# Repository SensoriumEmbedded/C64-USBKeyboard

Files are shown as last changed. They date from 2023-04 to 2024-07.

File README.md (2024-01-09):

# C64-USBKeyboard

## USB keyboard interface for Commodore 64

**Original code and C64 Key Pos Mapping:**
* C64keyboard - Commodore Keyboard library
* Copyright (c) 2022 Hartland PC LLC, Written by Robert VanHazinga

**Rewritten/updated for Teensy 3.6/4.1:**
* Copyright (c) 2023 Sensorium Embedded, Written by Travis Smith
* Raw keypresss detection for improved emulation
* Ability to Shift special macro keys to c64 (F2/4/6/8, Cursor up/left, etc) 
* Diagnostics loopback emulation
* Symbol mapping for readability and easy editing
* Improved code clarity, fixed bugs
* PCB designed/added

PCB assembly instructions can be found **[here.](PCB/PCB_Assembly.md)**

Questions?  Send e-mail to [Travis @ Sensorium](mailto:travis@sensoriumembedded.com)

Stand-alone and in-system pictures below.  Note that I have sockets above and below the Teensy module in my build. Actual build per BOM using headers will make it sit much lower (similar to the MT8808 chip)
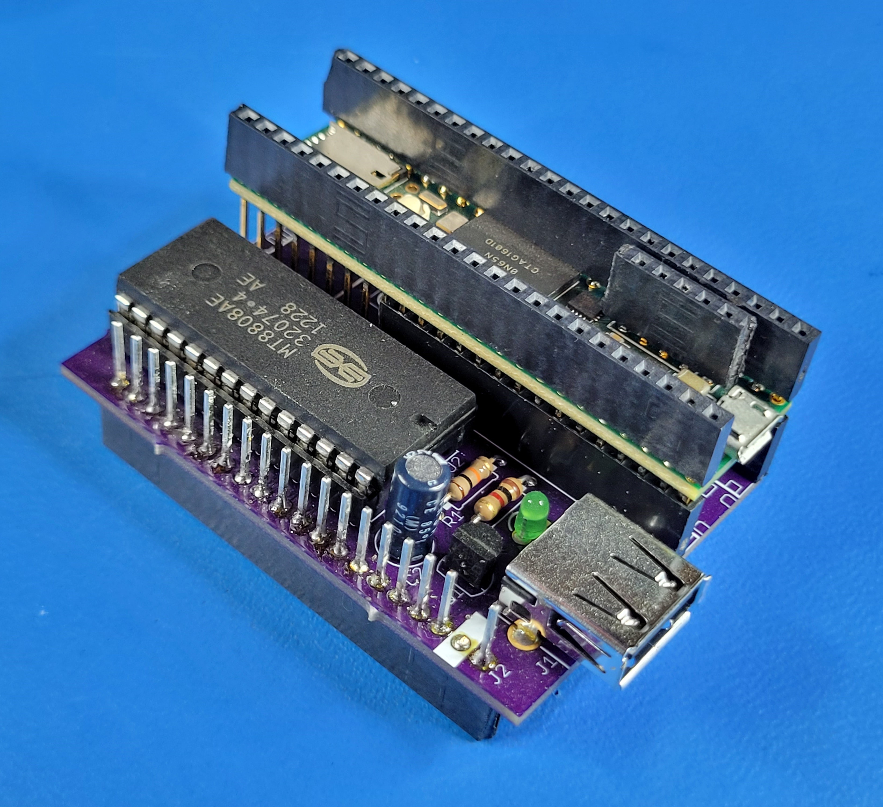
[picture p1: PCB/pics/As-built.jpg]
As-built
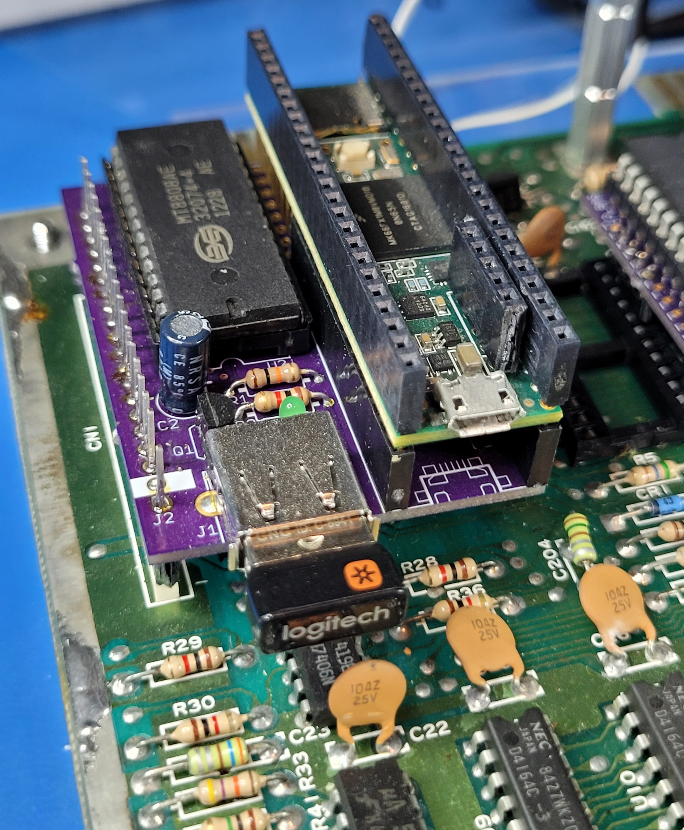
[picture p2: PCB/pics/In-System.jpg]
In-System
||| 
|:--:|:--:|

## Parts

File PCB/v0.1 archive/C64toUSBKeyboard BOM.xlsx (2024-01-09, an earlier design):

Qty | Ref Des | Value | Description | Manuf | MPN | DigiKey PN/link | Notes
1 |  | PCB | 2 layer 0.063" PCB | OSH Park, JLCPCB, PCBWay | v0.1 |  | C64toUSBKeyboard.0.1.gerbers.zip or https://oshpark.com/shared_projects/wqtal8dL
1 | R1 | 10k | RES 10K OHM 5% 1/4W AXIAL | Stackpole | CF14JT10K0 | CF14JT10K0CT-ND (https://www.digikey.com/en/products/detail/stackpole-electronics-inc/CF14JT10K0/1741265) | Multiple subs available
1 | R2 | 1k | RES 1K OHM 5% 1/4W AXIAL | Stackpole | CF14JT1K00 | CF14JT1K00CT-ND (https://www.digikey.com/en/products/detail/stackpole-electronics-inc/CF14JT1K00/1741314) | Multiple subs available
1 | J2 | 20p Female header | 20 Position Receptacle Connector 0.100" (2.54mm) Through Hole Tin w/ long pins | Samtec Inc. | SSQ-120-03-T-S | SAM1206-20-ND (https://www.digikey.com/en/products/detail/samtec-inc/SSQ-120-03-T-S/1111938) | Allows for passthrough to use simultaneous with commodore kbd, otherwise can just use standard female or cut leads
1 | C2 | 22uF | 22-100uF CPOL-US E2.5-6 Radial Electrolytic Cap | Panasonic | ECA-1EM220I | P19523CT-ND (https://www.digikey.com/en/products/detail/panasonic-electronic-components/ECA-1EM220I/2688679) | Multiple subs available
1 | Q1 | 2N3904 | NPN TRANSISTOR 2N3904/TO92 | Fairchild | 2N3904 | 3845-2N3904-ND (https://www.digikey.com/en/products/detail/galco-industrial-electronics/2N3904/15657702) | Multiple subs available
1 | C1 | DNS | Unused, Do Not Stuff
1 | D1 | LED-3MM-GRN | LED 3.1MM PTH | Lumex Opto | SSL-LX3044GD | 67-1060-ND (https://www.digikey.com/en/products/detail/lumex-opto-components-inc/SSL-LX3044GD/270858) | Sq hole/short lead/flat side/-/Cathode
1 | U2 | MT8808 | MITEL/ZARLINK MT8808AE DIP-28 ISO-CMOS 8 x 8 Analog Switch | MITEL/ZARLINK | MT8808AE | Multiple on eBay | No longer manufactured, but widely available.
1 | JP1 | SHORTSMT | Unused, Do Not Stuff |  |  |  | Leave this shorted, as designed
1 | U1 | TEENSY_4.1 | Teensy 4.1 Devel Board | PJRC (https://www.pjrc.com/store) | TEENSY41 or TEENSY41_NE (https://www.pjrc.com/store/teensy41.html) | 1568-DEV-16771-ND (https://www.digikey.com/en/products/detail/sparkfun-electronics/DEV-16771/12180099) | Teensy 3.6 would also work, but discontinued Teensy 4.1 with or without Ethernet will also work can order _PINS version to include soldered headers
2 | U1- Hdr 1/2 | 24p headers | CONN HEADER VERT 1x24 POS 2.54mm (0.1") | Würth | 61302411121 | 732-5331-ND (https://www.digikey.com/en/products/detail/w%C3%BCrth-elektronik/61302411121/4846867) | 24 pin headers to pass control signals from Teensy to PCB. Not needed with _PINS version of Teensy 4.1
1 | U1- Hdr 3 | 5p header | CONN HEADER VERT 1x5 POS 2.54mm (0.1") | Würth | 61300511121 | 732-5318-ND (https://www.digikey.com/en/products/detail/w%C3%BCrth-elektronik/61300511121/4846831) | 5 pin header to pass USB host signals from Teensy to PCB
1 | J1 | USB-A Fem | AMP connector | TE/AMP | 292303-1 | A31726-ND (https://www.digikey.com/en/products/detail/te-connectivity-amp-connectors/292303-1/773786)

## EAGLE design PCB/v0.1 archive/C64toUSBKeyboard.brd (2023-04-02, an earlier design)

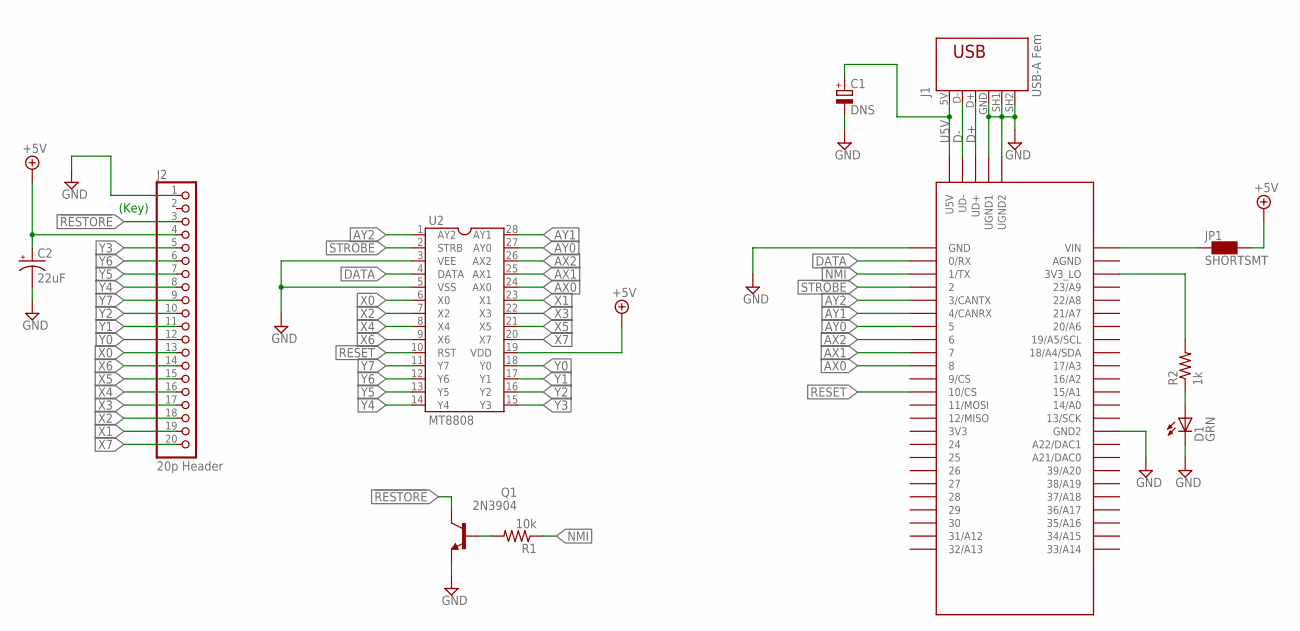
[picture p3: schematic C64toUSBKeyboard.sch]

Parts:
C1: DNS; A/3216-18W
C2: 22uF; E2,5-6
D1: GRN; LED-3MM-PTH
J1: USB-A Fem; USB
J2: 20p Header; 1X20_ROUND
JP1: SHORTSMT; SHORT
Q1: 2N3904; TO92
R1: 10k; 0207/10
R2: 1k; 0207/10
U1: TEENSY_3.6_4.1; TEENSY_3.5/3.6
U2: MT8808; DIL28-6

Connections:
3V3: R2.2, U1.3V3_LO
5V_TEENSY: JP1.1, U1.VIN
!RESTORE: J2.3, Q1.1 (C)
+5V: C2.+, J2.4, JP1.2, U2.19 (VDD)
AX0: U1.8, U2.24 (AX0)
AX1: U1.7, U2.25 (AX1)
AX2: U1.6, U2.26 (AX2)
AY0: U1.5, U2.27 (AY0)
AY1: U1.4/CANRX, U2.28 (AY1)
AY2: U1.3/CANTX, U2.1 (AY2)
D+: J1.D+ (3), U1.UD+
D-: J1.D- (2), U1.UD-
DATA: U1.0/RX, U2.4 (DATA)
GND: C1.-, C2.-, D1.K (C), J1.GND (4), J1.SH1 (5), J1.SH2 (6), J2.1, Q1.3 (E), U1.GND, U1.GND2, U1.UGND1, U1.UGND2, U2.3 (VEE), U2.5 (VSS)
LED_R: D1.A, R2.1
NMI: R1.1, U1.1/TX
NMI_R: Q1.2 (B), R1.2
RESET: U1.10/CS, U2.10 (RST)
STROBE: U1.2, U2.2 (STRB)
U5V: C1.+, J1.5V (1), U1.U5V
X0: J2.13, U2.6 (X0)
X1: J2.19, U2.23 (X1)
X2: J2.18, U2.7 (X2)
X3: J2.17, U2.22 (X3)
X4: J2.16, U2.8 (X4)
X5: J2.15, U2.21 (X5)
X6: J2.14, U2.9 (X6)
X7: J2.20, U2.20 (X7)
Y0: J2.12, U2.18 (Y0)
Y1: J2.11, U2.17 (Y1)
Y2: J2.10, U2.16 (Y2)
Y3: J2.5, U2.15 (Y3)
Y4: J2.8, U2.14 (Y4)
Y5: J2.7, U2.13 (Y5)
Y6: J2.6, U2.12 (Y6)
Y7: J2.9, U2.11 (Y7)

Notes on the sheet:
(Key)

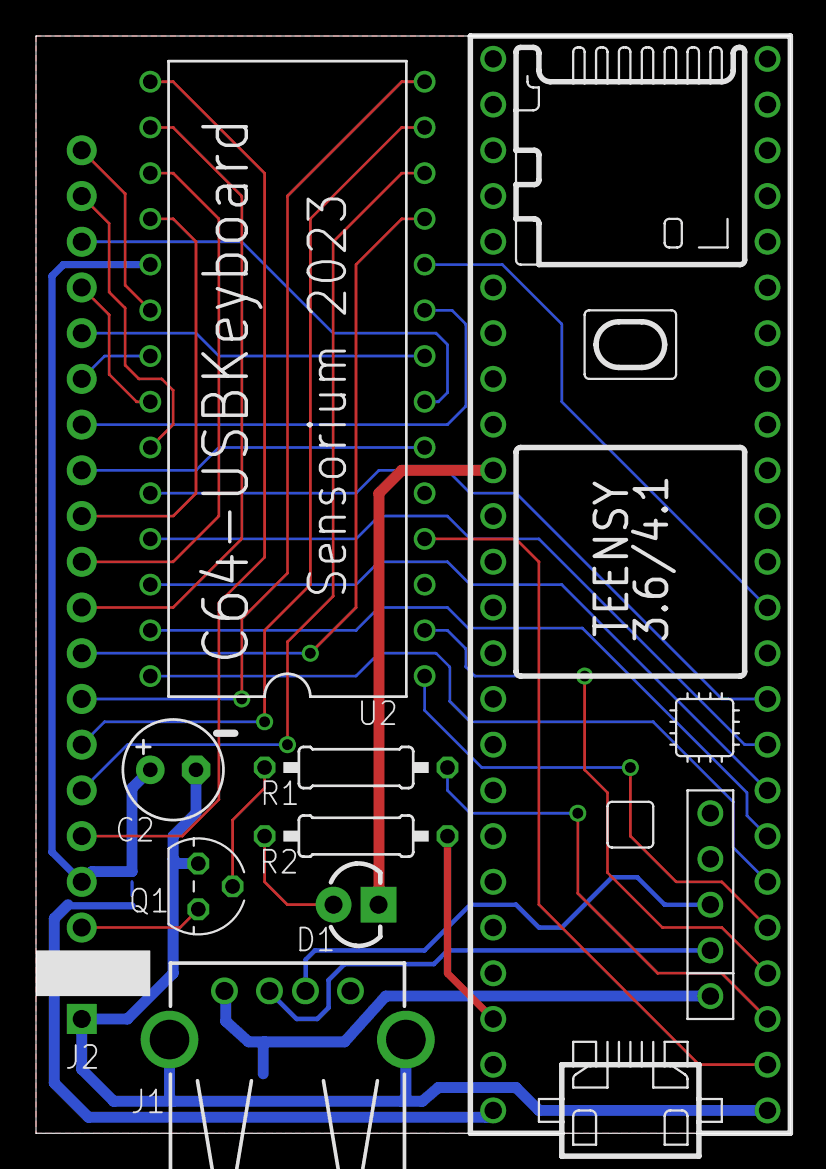
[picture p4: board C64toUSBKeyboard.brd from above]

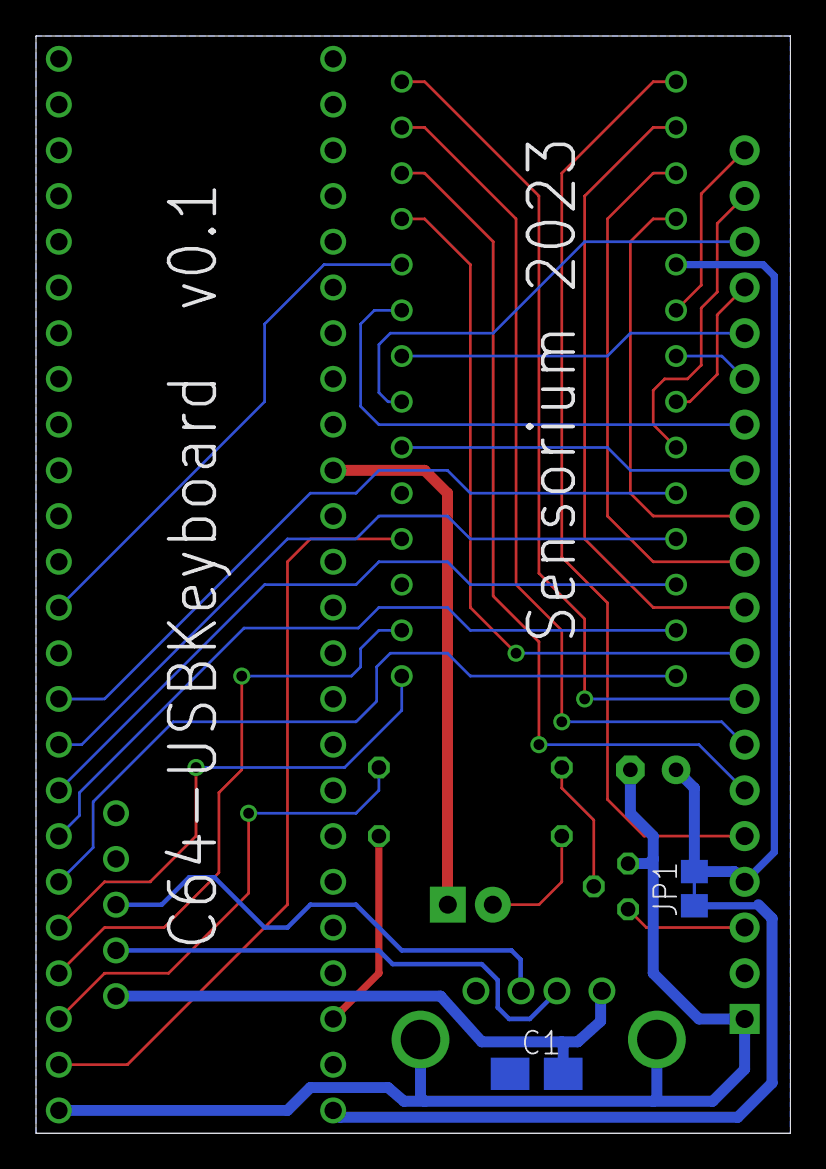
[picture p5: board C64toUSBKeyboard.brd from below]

Board: 2 copper layers, 41.9 x 61.0 mm, 11 parts (2 on the bottom side), 36 nets.

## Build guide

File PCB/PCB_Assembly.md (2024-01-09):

# C64 USB Keyboard PCB Assembly Instructions:

If there are additional questions, feel free to [contact me](mailto:travis@sensoriumembedded.com).

## Tools/materials needed:
- Soldering iron/Solder (lead-free or otherwise)
- Wire cutters (aka Side Cutters, Dykes)
- Small knife (ie Exacto)
- Computer with [Arduino](https://www.arduino.cc/en/software) and the [Teensyduino app](https://www.pjrc.com/teensy/td_download.html) loaded.
- Parts listed in the [TeensyROM BOM](https://github.com/SensoriumEmbedded/C64-USBKeyboard/raw/main/PCB/v0.1%20archive/C64toUSBKeyboard%20BOM.xlsx)
  - Including bare PCB: [Link to design at OSH Park](https://oshpark.com/shared_projects/wqtal8dL)

## Teensy prep:
- Programming the Teensy is done via the micro-USB connector on the Teensy itself.  This can create a problem with the 5v supply from the USB port driving against the 5v supply from your C64. Depending on how often you plan to update the firmware, choose one of the following two options.
  - **Option 1 (recommended)**: For the ability to update firmware while connected to the C64 (with the C64 turned on, powering the Teensy), you’ll need to cut a small jumper on the bottom of the Teensy 4.1 itself, as shown in [this picture](https://raw.githubusercontent.com/SensoriumEmbedded/TeensyROM/main/media/Teensy/T41_pwr_cut.jpg).  This should be done prior to assembly since it is on the bottom of the Teensy module.  The jumper can remain cut and allows programming while powered from the C64 only.
  - **Option 2**: Remove the PCB from the C64 when programming the Teensy.  This will allow the USB 5v to power the Teensy for programming and not conflict with the C64 power.  When finished, disconnect the micro-USB connection and re-install in to your C64.  **Do not connect the Teensy to a modern computer and the C64 at the same time when using this option.**
 
## PCB Assembly

- All components (except resistors) must be installed in propper orientation/polarity.
  - See silkscreen markings for each component during installation.
  - Capacitor (C2): Negative mark on cap should match negative mark on PCB
  - LED (D1): Square hole = short lead = flat side = Cathode
- Note that the Teensy requires both the two 24 pin headers as well as a 5 pin header to connect to the PCB. The 5 pin header carries the USB host signals to the connector, **(very important)**
- The connector to the C64(J2) is the only one installed from the bottom.

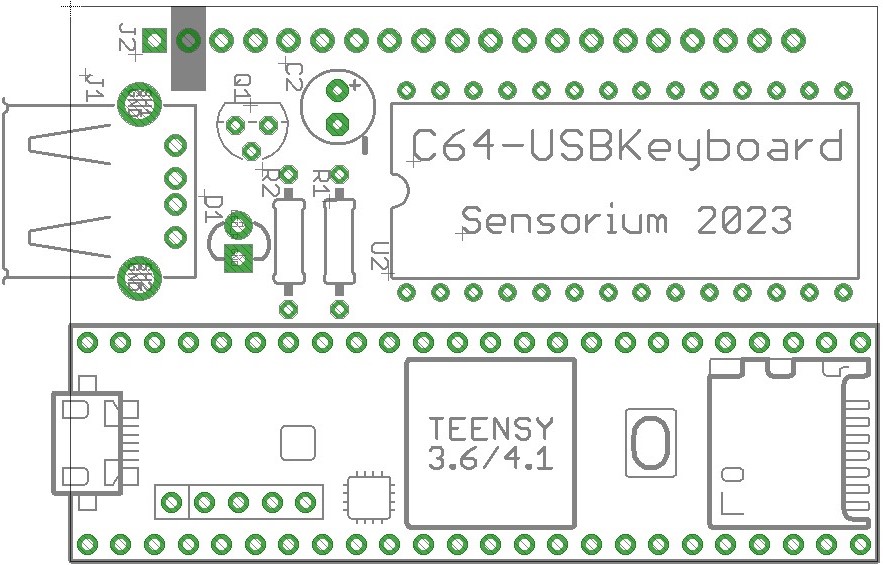
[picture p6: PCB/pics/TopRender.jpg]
TopRender


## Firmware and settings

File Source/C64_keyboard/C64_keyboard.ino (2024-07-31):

/*
  C64 USB keyboard - Commodore USB Keyboard Interface

  Rewritten for Teensy 3.6/4.1 and added:
    Raw keypresss detection, Shift special keys, symbol mapping, clarity, & bug fixes
    Copyright (c) 2023 Sensorium Embedded
    Written by Travis Smith

  Original code and C64 Key Pos Mapping:
    C64keyboard - Commodore Keyboard library
    Copyright (c) 2022 Hartland PC LLC
    Written by Robert VanHazinga

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
*/

#include "C64keyboard.h"
#include <USBHost_t36.h>

USBHost usb;
USBHub hub1(usb);
KeyboardController keyboard(usb);
USBHIDParser hid1(usb);
USBHIDParser hid2(usb);
IntervalTimer TODTimer;

bool CapsLockState=false; 
bool TODClockState=false;
bool TOD60n50HzSel=true;

extern "C" uint32_t set_arm_clock(uint32_t frequency);

void setup() 
{
   usb.begin();
   
   for ( uint8_t AddrBit = 0; AddrBit < 6; AddrBit++) pinMode(MT8808_ADDRESS_PINS[AddrBit], OUTPUT);
   pinMode(MT8808_STROBE_PIN, OUTPUT);
   pinMode(MT8808_DATA_PIN, OUTPUT);  
   pinMode(MT8808_RESET_PIN, OUTPUT); 
   pinMode(NMI_RESTORE_PIN, OUTPUT);  
   pinMode(INDICATOR_LED_PIN, OUTPUT);
   pinMode(EXT_TOD_CLK_OUT_PIN, OUTPUT);
   
   digitalWrite(NMI_RESTORE_PIN, LOW);
   digitalWrite(MT8808_STROBE_PIN, LOW);
   digitalWrite(INDICATOR_LED_PIN, HIGH);
   ResetMT8808();
   
   keyboard.attachRawPress(OnRawPress);
   keyboard.attachRawRelease(OnRawRelease);
   
   TODTimer.begin(ToggleTOD, IntervaluS_60Hz);  // Default to 60Hz
   
   Serial.begin(9600);
   
   Serial.println("\n\nUSB Keyboard -> Teensy -> MT8808 -> C64 keyboard input");
   digitalWrite(INDICATOR_LED_PIN, LOW);
   #ifdef ARDUINO_TEENSY41
      set_arm_clock(180000000);  //slow down Teensy 4.1 to match 3.6 default, otherwise too fast for 8808.  
         //Could add delays to SetSwitch, but slower CPU runs cooler and uses less power
      Serial.println("Teensy 4.1 found");
   #endif
}

void loop() 
{  
   usb.Task(); // Process USB tasks
}

void OnRawPress(uint8_t keycode) 
{
   digitalWrite(INDICATOR_LED_PIN, HIGH);
   Serial.print("Press==");
   ConvToC64Key(keycode, true);
}

void OnRawRelease(uint8_t keycode) 
{
   Serial.print("Release");
   ConvToC64Key(keycode, false);
   digitalWrite(INDICATOR_LED_PIN, LOW);
}

void ResetMT8808(void) 
{
   digitalWrite(MT8808_RESET_PIN, HIGH);
   digitalWrite(MT8808_RESET_PIN,  LOW);
   CapsLockState = false;
}

void ConvToC64Key(uint8_t KeyCode, bool KeyIsPressed) 
{
   Serial.printf ("=> USB Code: %d=0x%X, Press: %d\n", KeyCode, KeyCode, KeyIsPressed);
 
   // check for special USB scan codes
   if (KeyCode == F12_MT8808_RESET_KEY && KeyIsPressed) 
   {
      ResetMT8808();  
      Serial.println("  *MT8808 Reset");
      return;
   }   
   
   if (KeyCode == F11_LOOPBACK_KEY && KeyIsPressed) 
   {
      ResetMT8808();  
      uint8_t LoopSwitches[]={0x00, 0x09, 0x12, 0x1b, 0x24, 0x2d, 0x36, 0x3f};
      for(uint8_t SWNum=0; SWNum<sizeof(LoopSwitches); SWNum++) SetSwitch(LoopSwitches[SWNum],1);
      Serial.println("  *Loopback Mode");
      return;
   }   
   
   if (KeyCode == F10_PULSE_OUTPUT && KeyIsPressed) 
   {
      //drive output low, then tri-state (open collector emulation)
      digitalWrite(EXT_PULSE_OUT_PIN , 0);
      pinMode(EXT_PULSE_OUT_PIN, OUTPUT);
      delay(50);
      pinMode(EXT_PULSE_OUT_PIN, INPUT);
      Serial.println("  *Output Pulsed");
      return;
   }
   
   if (KeyCode == F9_TOD_50_60HzTOGGLE && KeyIsPressed) 
   {
      // toggle TOD output pin timer between 50 and 60Hz
      TOD60n50HzSel = !TOD60n50HzSel;
      TODTimer.update((TOD60n50HzSel ? IntervaluS_60Hz : IntervaluS_50Hz));
      Serial.printf("  *changed TOD clk to %d0Hz\n", (TOD60n50HzSel ? 6 : 5 ));
      return;
   }
   
   if (KeyCode == TAB_RESTORE_KEY)
   {
     digitalWrite (NMI_RESTORE_PIN, KeyIsPressed);
     Serial.printf("  *Restore Key state: %d\n", KeyIsPressed);
     return;
   }
   
   if (KeyCode == CAPSLOCK_TOG_KEY && KeyIsPressed) 
   {
     CapsLockState = !CapsLockState;
     SetSwitch(C64KP_L_SHIFT, CapsLockState);
     Serial.printf("  *Caps Lock state: %d\n", CapsLockState);
     return;
   }

   // Process Key     
   if(KeyCode >= sizeof(KeyCodeToC64Map)) return; //out  of range?
   
   uint8_t C64KeyMap = KeyCodeToC64Map[KeyCode]; 
   if (C64KeyMap == C64KP_IGNORE) return; //ignore?
   
   if (C64KeyMap & SHIFT) //Special function to make sure key is shifted to c64
   {
      if (KeyIsPressed) SetSwitch(C64KP_R_SHIFT, 1); // press before...
      SetSwitch(C64KeyMap, KeyIsPressed); 
      if (!KeyIsPressed) SetSwitch(C64KP_R_SHIFT, 0); // ...release after
      return;
   }
   
   SetSwitch(C64KeyMap, KeyIsPressed); //normal case
}

void SetSwitch(uint8_t C64KeyMap, bool KeyState)
{
   C64KeyMap &= 63;  //strip upper bits
   
   digitalWrite(MT8808_DATA_PIN , KeyState);
   for ( uint8_t AddrBit = 0; AddrBit < 6; AddrBit++) digitalWrite(MT8808_ADDRESS_PINS[AddrBit], C64KeyMap & (1<<AddrBit));
   digitalWrite( MT8808_STROBE_PIN, HIGH);
   digitalWrite( MT8808_STROBE_PIN, LOW);
   
   Serial.printf ("  *Switch: C64 KeyMap: %d, State: %d\n", C64KeyMap, KeyState);
}
      
void ToggleTOD()
{
   digitalWrite(EXT_TOD_CLK_OUT_PIN, TODClockState = !TODClockState);   
}

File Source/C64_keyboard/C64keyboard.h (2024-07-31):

/*
  C64 USB keyboard - Commodore USB Keyboard Interface

  Rewritten for Teensy 3.6/4.1 and added:
    Raw keypresss detection, Shift special keys, symbol mapping, clarity, & bug fixes
    Copyright (c) 2023 Sensorium Embedded
    Written by Travis Smith

  Original code and C64 Key Pos Mapping:
    C64keyboard - Commodore Keyboard library
    Copyright (c) 2022 Hartland PC LLC
    Written by Robert VanHazinga

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
*/


//Teensy Pin Mapping
#define MT8808_DATA_PIN        0 // Sets selected cross switch on/off
#define NMI_RESTORE_PIN        1 // NMI (RESTORE KEY) PIN
#define MT8808_STROBE_PIN      2 // Strobe timing pulse (active high)
#define MT8808_RESET_PIN      10 // Reset all MT8808 cross switches to off (active high)
#define INDICATOR_LED_PIN     13 // LED on the Teensy
#define EXT_PULSE_OUT_PIN     32 // External Open Collector pulse low to simulate TeensyROM menu button push
#define EXT_TOD_CLK_OUT_PIN   25 // 50/60Hz TOD clock output to inject into CIAs

const uint8_t MT8808_ADDRESS_PINS[] = 
{
                               3,  // AY2
                               4,  // AY1
                               5,  // AY0
                               6,  // AX2
                               7,  // AX1
                               8,  // AX0
};

#define IntervaluS_50Hz    10000 //  1/50/2*1000000
#define IntervaluS_60Hz     8333 //  1/60/2*1000000

//C64 Key Pos Symbols:
//6 bit encoded switch matrix location, 3 bits for the X value and 3 bits for the Y
// bit 0: AY2
// bit 1: AY1
// bit 2: AY0
// bit 3: AX2
// bit 4: AX1
// bit 5: AX0
// bit 7: special value for keys that must be shifted (f2, etc), see KeyCodeToC64Map
// bit 6: Key map value to ignore key press
#define C64KP_1               0x38  // 56
#define C64KP_2               0x3E  // 62
#define C64KP_3               0x20  // 32
#define C64KP_4               0x26  // 38
#define C64KP_5               0x10  // 16
#define C64KP_6               0x16  // 22
#define C64KP_7               0x30  // 48
#define C64KP_8               0x36  // 54
#define C64KP_9               0x08  // 8
#define C64KP_A               0x22  // 34
#define C64KP_B               0x31  // 49
#define C64KP_C               0x11  // 17
#define C64KP_D               0x12  // 18
#define C64KP_E               0x23  // 35
#define C64KP_F               0x15  // 21
#define C64KP_G               0x32  // 50
#define C64KP_H               0x35  // 53
#define C64KP_I               0x0C  // 12
#define C64KP_J               0x0A  // 10
#define C64KP_K               0x0D  // 13
#define C64KP_L               0x2A  // 42
#define C64KP_M               0x09  // 9
#define C64KP_N               0x0F  // 15
#define C64KP_O               0x0B  // 11
#define C64KP_P               0x2C  // 44
#define C64KP_Q               0x3B  // 59
#define C64KP_R               0x14  // 20
#define C64KP_S               0x25  // 37
#define C64KP_T               0x13  // 19
#define C64KP_U               0x33  // 51
#define C64KP_V               0x37  // 55
#define C64KP_W               0x24  // 36
#define C64KP_X               0x17  // 23
#define C64KP_Y               0x34  // 52
#define C64KP_Z               0x21  // 33
#define C64KP_AT              0x2B  // 43
#define C64KP_F1              0x01  // 1
#define C64KP_F3              0x05  // 5
#define C64KP_F5              0x03  // 3
#define C64KP_F7              0x06  // 6
#define C64KP_DEL             0x00  // 0
#define C64KP_RTN             0x04  // 4
#define C64KP_CTRL            0x3A  // 58
#define C64KP_HOME            0x1E  // 30
#define C64KP_PLUS            0x28  // 40
#define C64KP_ZERO            0x0E  // 14
#define C64KP_COLON           0x2D  // 45
#define C64KP_COMMA           0x2F  // 47
#define C64KP_EQUAL           0x1D  // 29
#define C64KP_MINUS           0x2E  // 46
#define C64KP_POUND           0x18  // 24
#define C64KP_SLASH           0x1F  // 31
#define C64KP_SPACE           0x39  // 57
#define C64KP_ARR_UP          0x1B  // 27
#define C64KP_PERIOD          0x29  // 41
#define C64KP_L_SHIFT         0x27  // 39
#define C64KP_R_SHIFT         0x19  // 25
#define C64KP_SEMICOL         0x1A  // 26
#define C64KP_ARR_LEFT        0x3C  // 60
#define C64KP_ASTERISK        0x1C  // 28
#define C64KP_HORZ_CSR        0x02  // 2
#define C64KP_RUN_STOP        0x3F  // 63
#define C64KP_VERT_CSR        0x07  // 7
#define C64KP_COMMODORE       0x3D  // 61

//special function c64 keymap codes/mods:
#define C64KP_IGNORE          0x80 // Dec 128: C64 Key map value to ignore key press
#define SHIFT                 0x40 // Dec 64: When bit set, special value that must be shift (f2, etc)
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

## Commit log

2023-04-02 v0.1 PCB design in Eagle PCB
    [C64toUSBKeyboard BOM.xlsx, C64toUSBKeyboard.brd, C64toUSBKeyboard.sch]
2023-04-06 Rewritten for Raw Key Press Improved clarity license/author info update timing/initialization fixes keymap additions via +SHIFT option
    [C64_keyboard.ino, C64keyboard.h]
2023-04-06 ALT keys ignored, Esc becomes RUN/STOP
2023-04-09 Diag loopback mode added (F11)
    [C64toUSBKeyboard BOM.xlsx]
2023-10-17 Gerbers PCB files and BOM details added
    [C64toUSBKeyboard BOM.xlsx]
2024-01-09 Added Teensy connection headers to BOM, notes clarification
    [C64toUSBKeyboard BOM.xlsx]
2024-01-09 PCB assy instructions, Top Render picture
2024-01-18 New feature: F10 Pulses teensy pin 32 low, use for TeensyROM button Added USBHIDParser(s) for compatibility with latest library Added USBHub (in case used) Slowed down Teensy 4.1 (only) to 180MHz clo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
    [C64_keyboard.ino, C64keyboard.h]
2024-07-31 50/60Hz out of pin 25 for TOD clock injection. toggle freq with F9

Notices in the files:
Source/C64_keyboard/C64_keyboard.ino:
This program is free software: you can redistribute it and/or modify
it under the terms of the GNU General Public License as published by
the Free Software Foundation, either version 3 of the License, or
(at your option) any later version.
